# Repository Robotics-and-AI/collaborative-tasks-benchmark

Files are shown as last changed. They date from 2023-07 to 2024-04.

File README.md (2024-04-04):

# Collaborative Tasks Benchmark (CT Benchmark)
<p align="center">
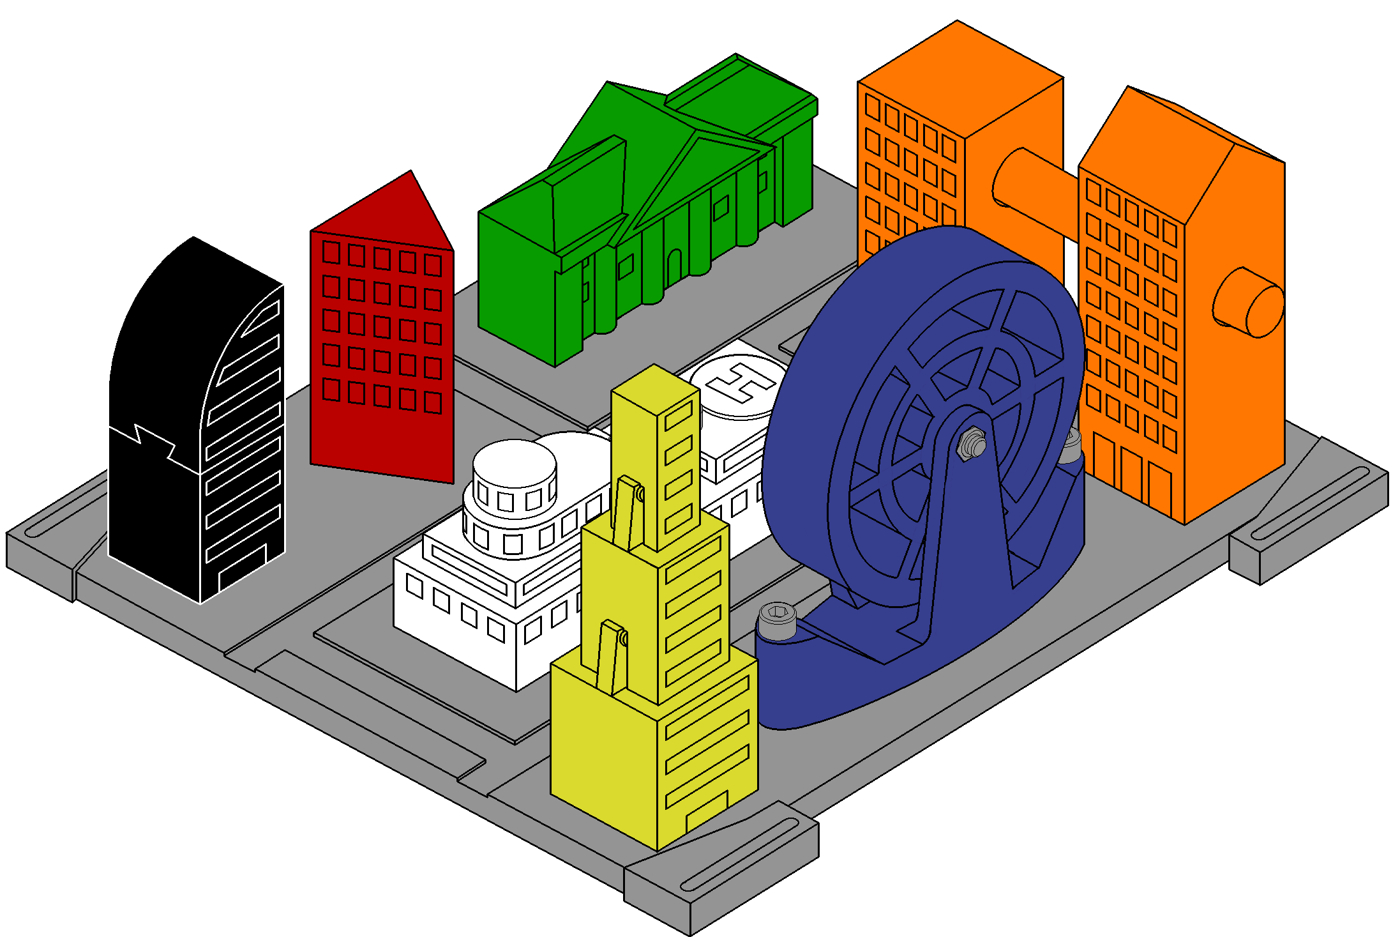
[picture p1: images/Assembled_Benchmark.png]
Assembled benchmark
    
</p>

## Introduction
Benchmarks are crucial to help robotics research advance in an efficient and standardized manner, however, the collaborative assembly field lacks a benchmark with multiple tasks of varying task complexity. As such, we propose the Collaborative Tasks Benchmark (CT Benchmark). It contains 7 distinct tasks ranging from easy to difficult assembly scenarios, each with 1 to 3 parts, providing a rich environment for studying collaborative assembly systems. Its design was grounded on the following criteria:

- Contain independent sequential assembly tasks 
- Tasks have a wide variety of sturdy and graspable 3D printable pieces
- Each piece has its own distinguishable features. 

The benchmark mainly focuses on assisting in the development of collaborative systems, though it is also applicable towards
any combination of its inherent sub-systems: task sequencing allocation, fully-robotic assembly, robot pick-and-place operations and visual perception.

## Task description
The proposed benchmark is representative of a city landscape and contains a total of 7 unique tasks. The main assembly operations are wide tolerance insertion (WTI), tight tolerance insertion (TTI), screw fastening, snap fitting and two-handed actions.

| Task | Color | # sub-tasks | # parts | WTI | TTI | Screw | Snap-fit | Two-handed |
| :---: | :---: | :---: | :-----: | :---: | :---: | :---: | :---: | :---: |
| Museum | green  | 1 | 1 | ✓ | | | | |
| Snap | yellow | 3 | 3 | ✓ | ✓ | | ✓ | |
| Bridge | orange | 3 | 3 | ✓ | ✓ | | | |
| Triangle | red | 1 | 1 | ✓ | | | | |
| Wheel | blue | 3 | 2 | ✓ | | ✓ | | ✓ |
| Dovetail | black  | 2 | 2 | ✓ | ✓ | | | |
| Hospital | white  | 4 | 3 | ✓ | | ✓ | | |

## Benchmark deployment

<table>
  <thead>
    <tr>
      <th>Essential hardware</th>
      <th>Optional hardware</th>
    </tr>
  </thead>
  <tbody>
    <tr>
      <td>
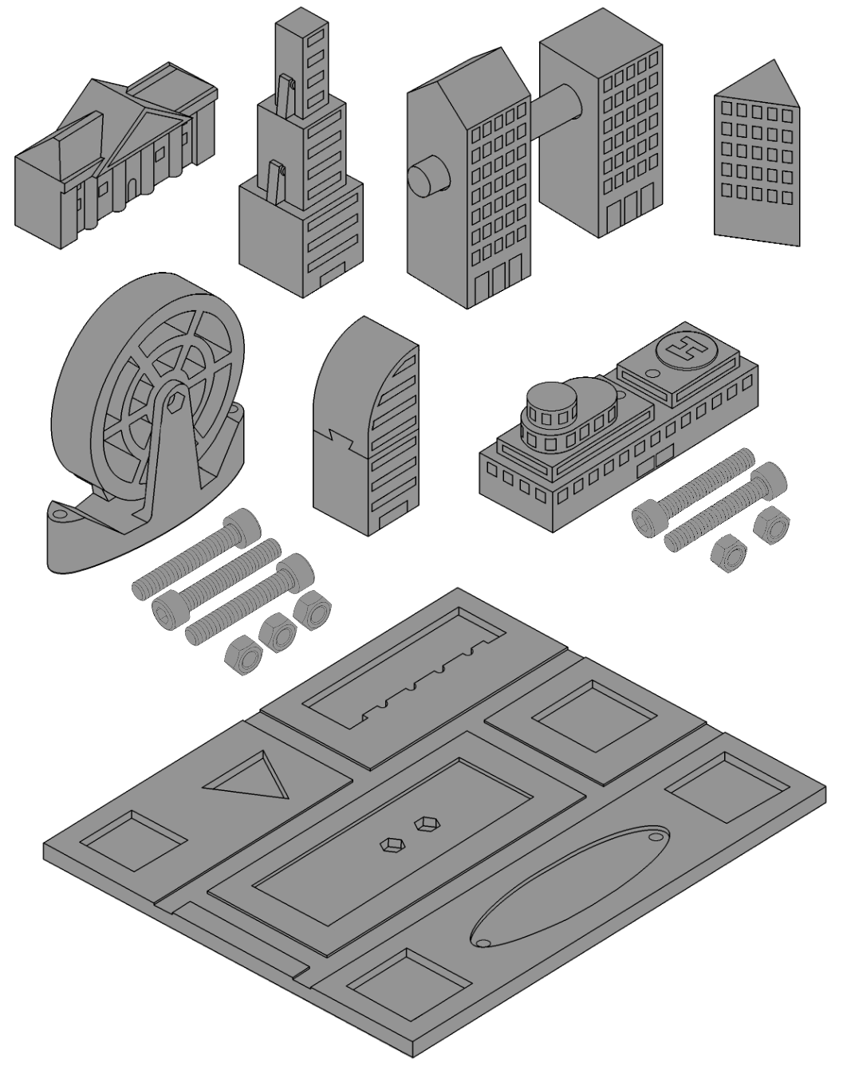
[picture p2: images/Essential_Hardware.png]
Essential Hardware
        
      </td>
      <td>
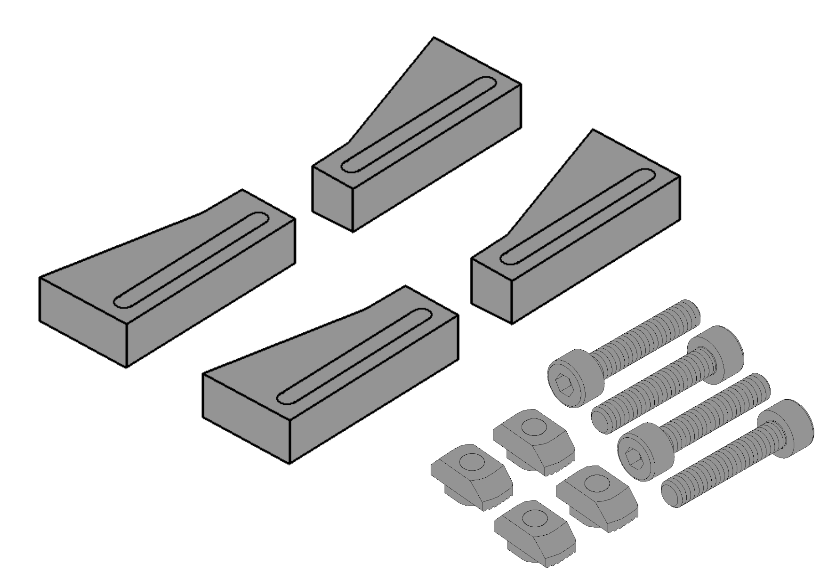
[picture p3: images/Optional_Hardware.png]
Optional Hardware
        
      </td>
    </tr>
    <tr>
      <td>
        <b>3D printed buildings and base:</b>
        <ul>
          <li>520g of PLA</li>
          <li>25 hours</li>
        </ul>
        <b>Fasteners:</b>
        <ul>
          <li>M5 x 30 screws (x5)</li>
          <li>ISO 4032 M5 nuts (x5)</li>
        </ul>
      </td>
      <td>
        <b>3D print corner pieces:</b>
        <ul>
            <li>20g of PLA</li>
            <li>1 hour</li>
          </ul>
          <b>Fasteners:</b>
          <ul>
            <li>M4 x 20 screws (x4)</li>
            <li>Adequately sized M4 T-nuts (x4)</li>
          </ul>
      </td>
    </tr>
  </tbody>
</table>

## Additional material
In addition to the essential and optional hardware, <a href="aditional_stl_files">three supports</a> are made available to aid the assembly process. 
These supports were used to guarantee a repeatable setup in the accompanying article while performing the proposed manufacturing assembly scenarios.

## Cite our paper
If you've found the CT Benchmark useful for your research, please cite our paper as follows:

```
@article{duarte2024benchmarking,
         title = {Benchmarking human-robot collaborative assembly tasks},
         author = {Laura Duarte and 
                   Miguel Neves and 
                   Pedro Neto},
         journal = {Results in Engineering},
         volume = {22},
         year = {2024},
         issn = {2590-1230},
         doi = {10.1016/j.rineng.2024.102042}
}
```

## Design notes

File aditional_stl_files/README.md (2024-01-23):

## Additional 3D printable supports

All supports can be fixed to a T-slot aluminium extrusion frame, with the use of screws and T-nuts.

## Part description

<table>
  
  <thead>
    <tr>
      <th>Image</th>
      <th>Intended use</th>
    </tr>
  </thead>
  
  <tbody>
    <tr>
      <td>
        <p align="center">
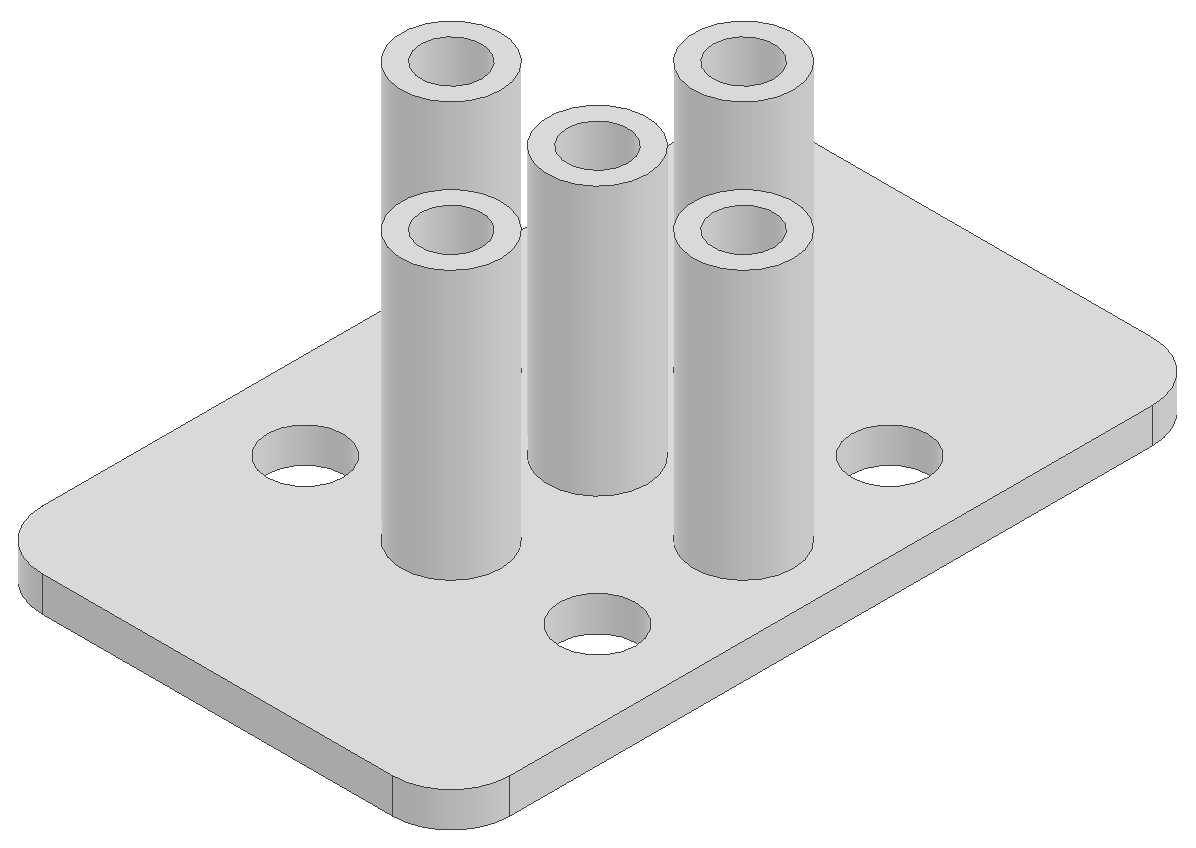
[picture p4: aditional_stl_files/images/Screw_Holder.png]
Screw holder
          </td>
        </p>
      <td>
        Hold the screws in an upright position for easy access to the user
        
        <b>Fasteners:</b>
          <ul>
            <li>M6 x 12 screws (x2)</li>
            <li>Adequately sized M6 T-nuts (x2)</li>
          </ul>
      </td>
    </tr>
    <tr>
      <td>
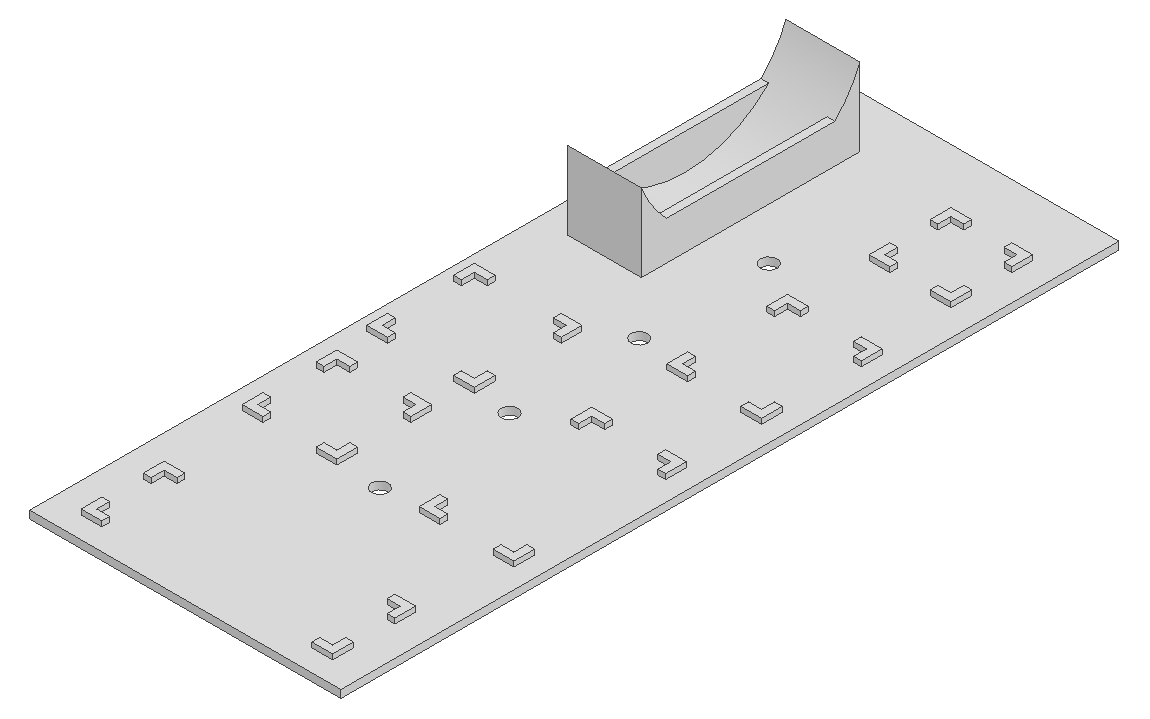
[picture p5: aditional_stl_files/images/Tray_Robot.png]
Tray for robot
          </td>
      <td>
        Hold the benchmark parts intended to be picked up by the collaborative robot
        
        <b>Fasteners:</b>
          <ul>
            <li>M6 x 12 screws (x4)</li>
            <li>Adequately sized M6 T-nuts (x4)</li>
          </ul>
      </td>
    </tr>
    <tr>
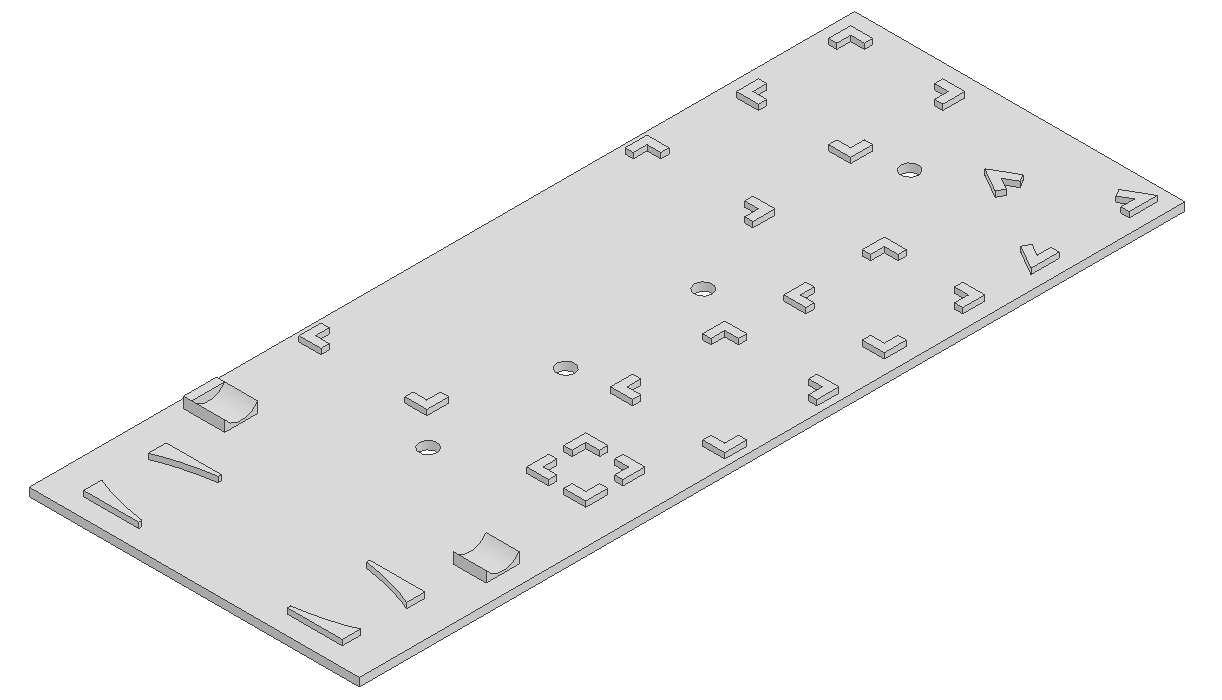
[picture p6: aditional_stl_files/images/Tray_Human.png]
Tray for human
      <td></td>
      <td>
        Hold the benchmark parts intended to be picked up by the human operator
        
        <b>Fasteners:</b>
          <ul>
            <li>M6 x 12 screws (x4)</li>
            <li>Adequately sized M6 T-nuts (x4)</li>
          </ul>
      </td>
    </tr>
  </tbody>
  
</table>

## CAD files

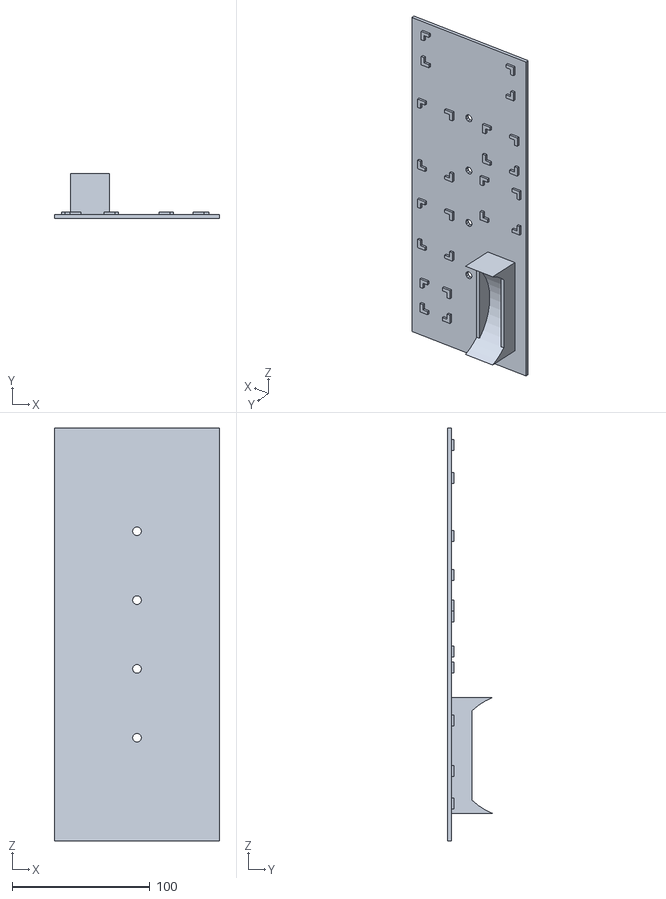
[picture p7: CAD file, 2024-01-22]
aditional_stl_files/stl_files/Tray_Robot.stl
120.0 x 33.0 x 300.0

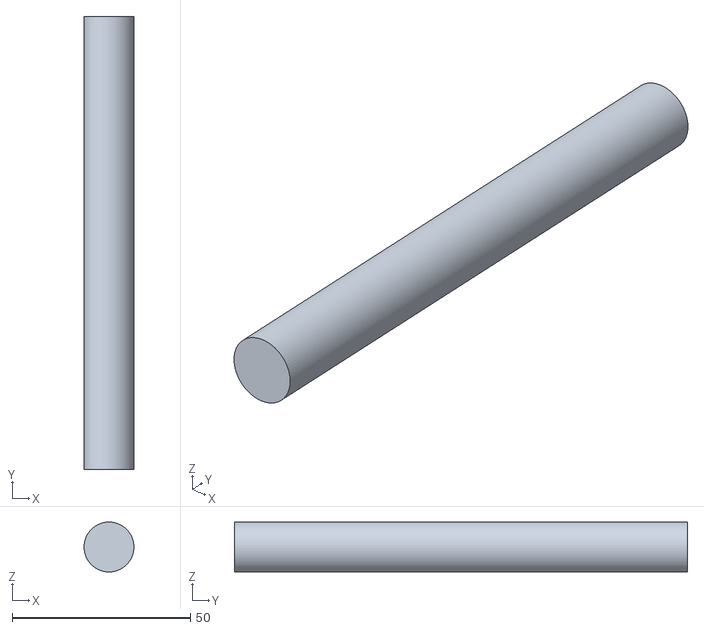
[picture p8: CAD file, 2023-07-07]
stl_files/Bridge/Bridge_Peg.stl
14.0 x 127.0 x 14.0

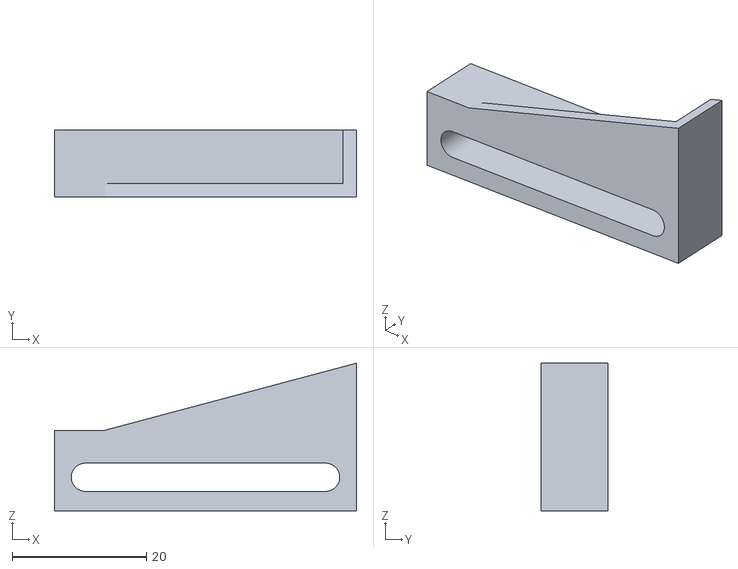
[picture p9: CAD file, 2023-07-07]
stl_files/Corner.stl
45.0 x 10.0 x 22.0

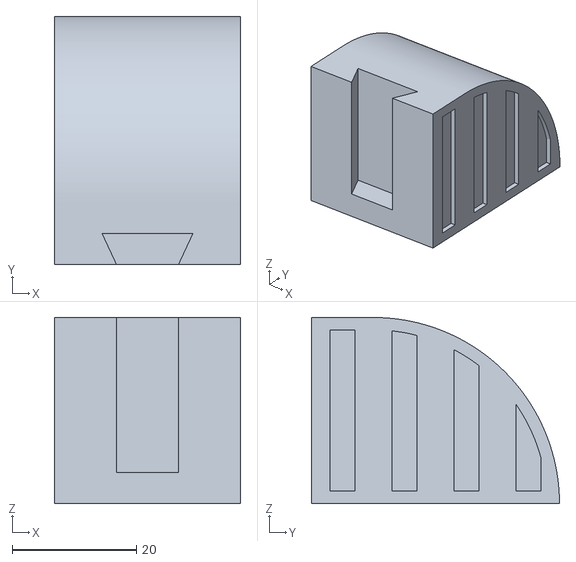
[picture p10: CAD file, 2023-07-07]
stl_files/Dovetail/Dovetail_Top.stl
30.0 x 40.0 x 30.0

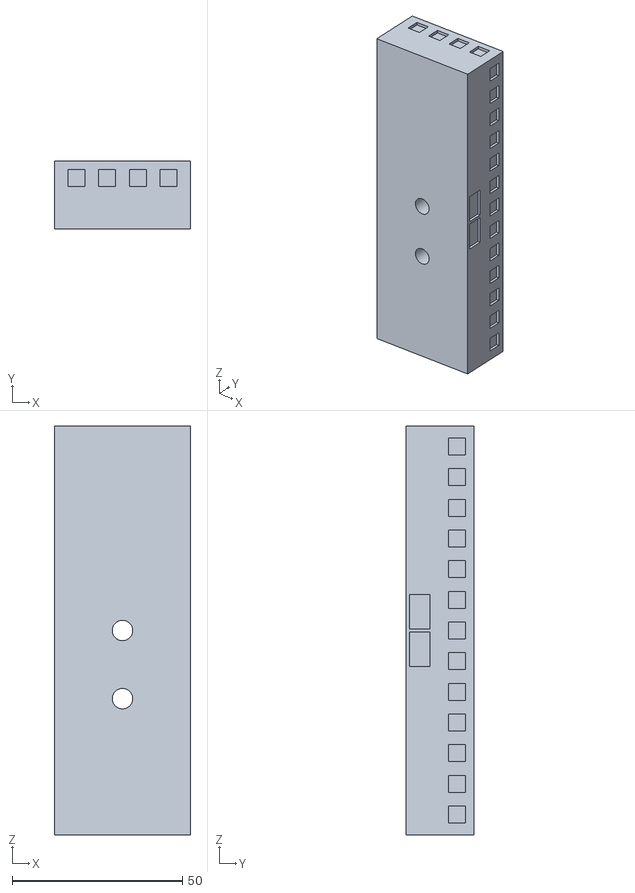
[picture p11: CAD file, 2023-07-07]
stl_files/Hospital/Hospital_Lower.stl
40.0 x 20.0 x 120.0

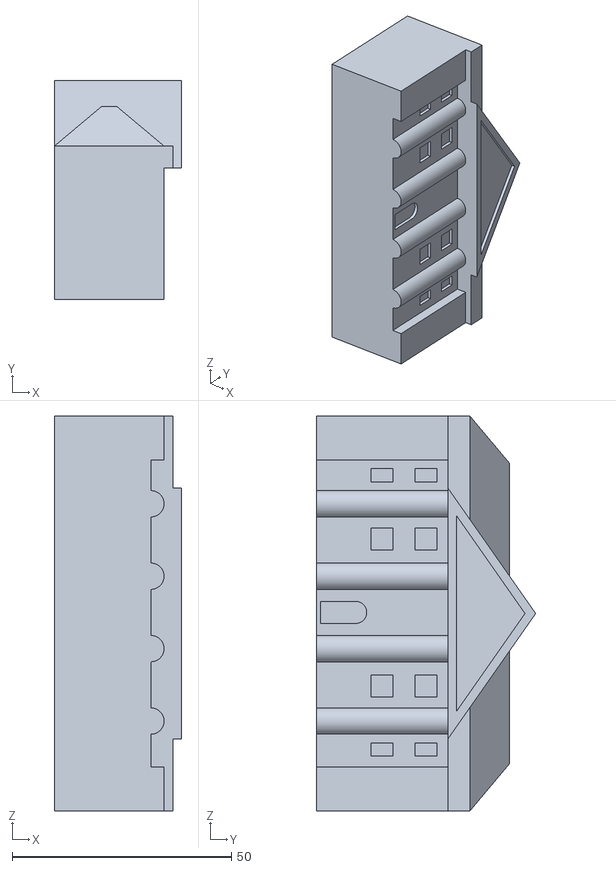
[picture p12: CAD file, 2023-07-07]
stl_files/Museum/Museum.stl
29.0 x 50.0 x 90.0

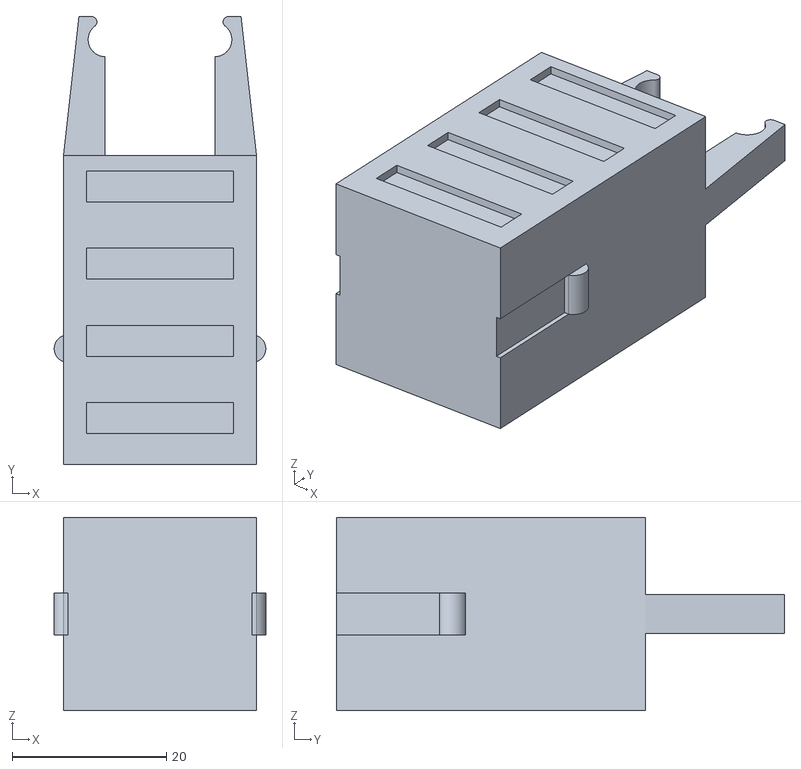
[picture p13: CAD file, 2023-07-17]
stl_files/Snap/Building_Snap_Middle.stl
27.4 x 58.0 x 25.0

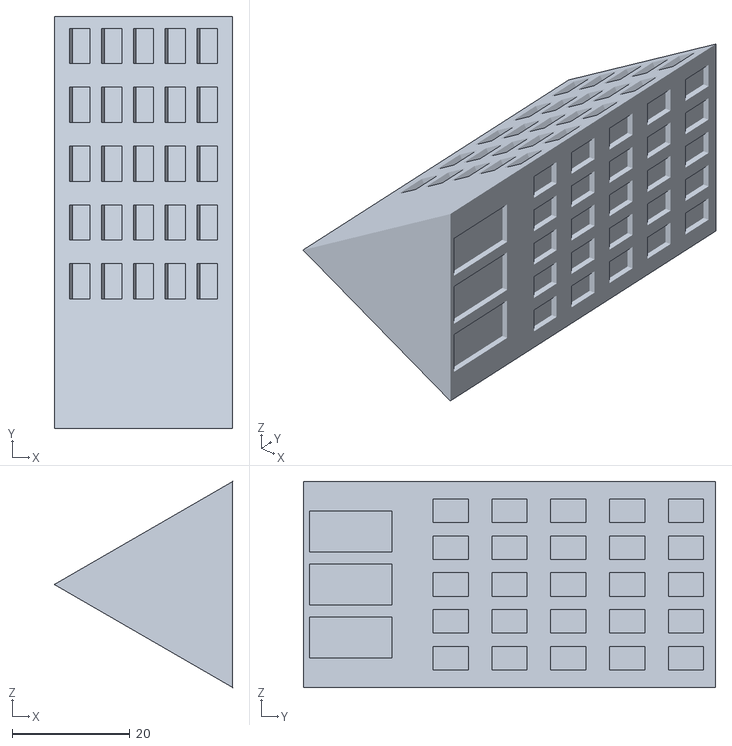
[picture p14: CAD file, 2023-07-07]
stl_files/Triangle/Building_Triangle.stl
30.3 x 70.0 x 35.0

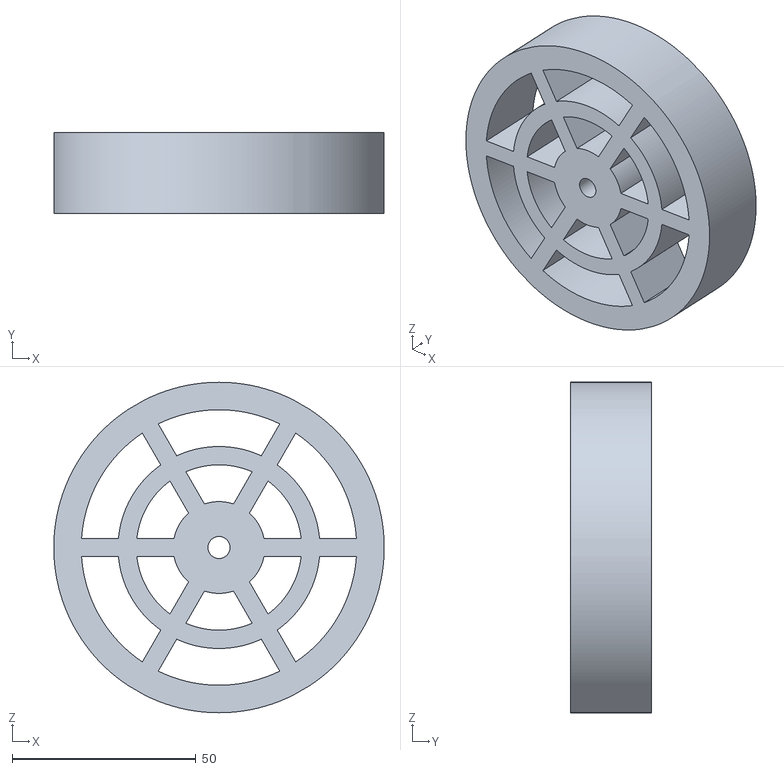
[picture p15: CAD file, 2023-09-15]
stl_files/Wheel/Wheel.stl
89.9 x 22.0 x 90.0

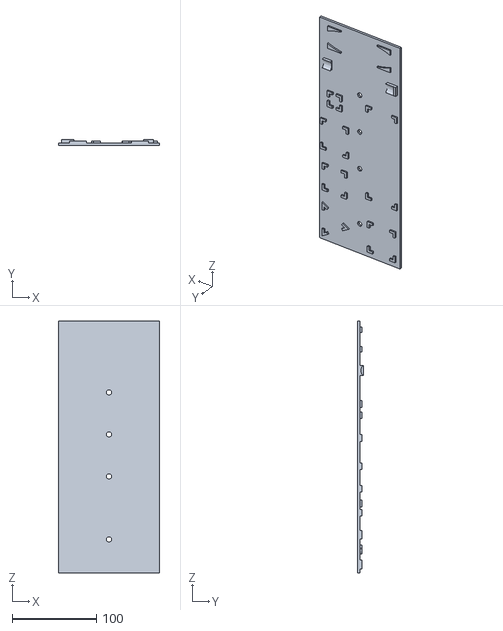
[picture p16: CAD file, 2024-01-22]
aditional_stl_files/stl_files/Tray_Human.stl
120.0 x 6.93 x 300.0

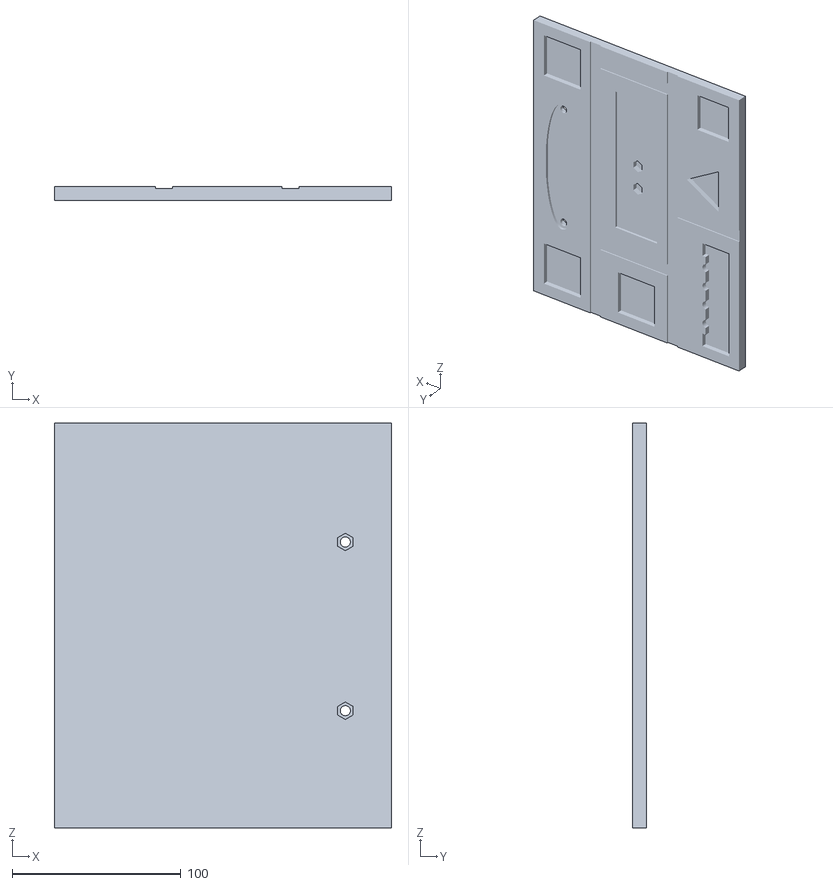
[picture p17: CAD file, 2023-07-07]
stl_files/Base.stl
200.0 x 8.00 x 240.0

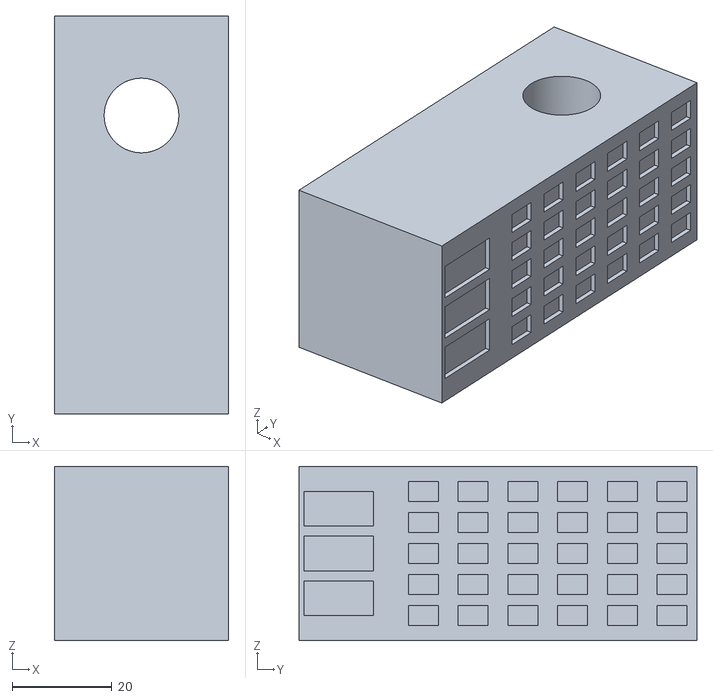
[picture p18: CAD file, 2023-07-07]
stl_files/Bridge/Bridge_Flat.stl
35.0 x 80.0 x 35.0

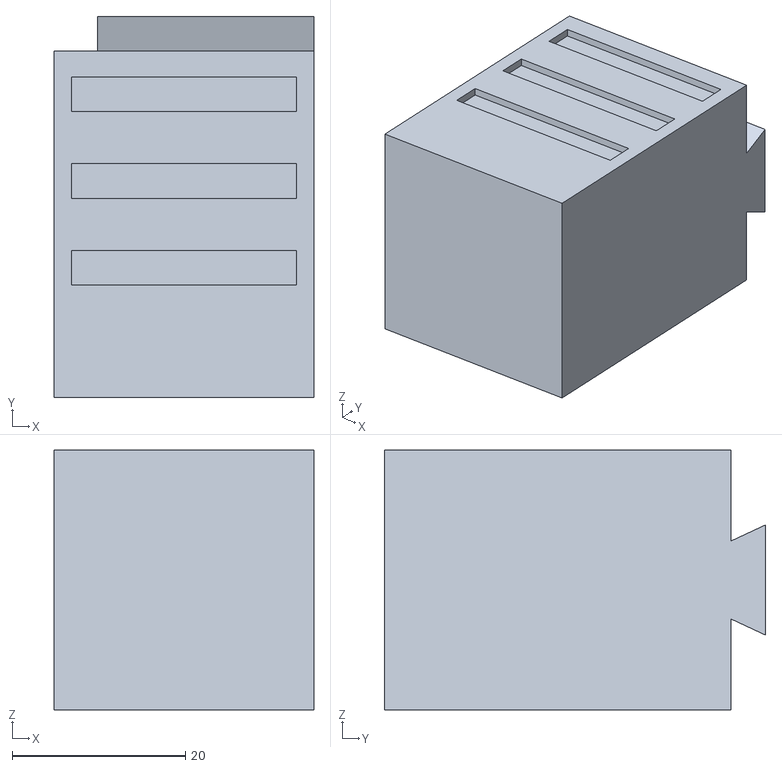
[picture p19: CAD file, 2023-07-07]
stl_files/Dovetail/Dovetail_Lower.stl
30.0 x 44.0 x 30.0

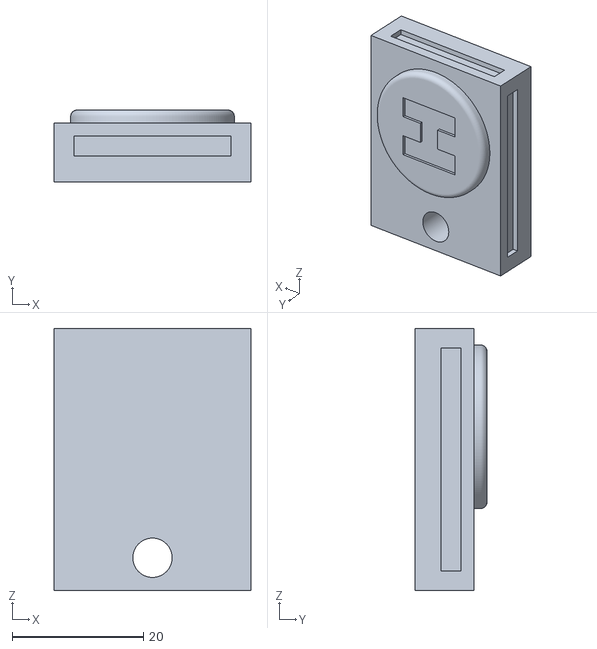
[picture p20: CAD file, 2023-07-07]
stl_files/Hospital/Hospital_Helipad.stl
30.0 x 11.0 x 40.0

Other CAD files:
stl_files/Snap/Building_Snap_Top.stl
stl_files/Wheel/Wheel_Base.stl
stl_files/Bridge/Bridge_Roof.stl
stl_files/Corner_MIR.stl
aditional_stl_files/stl_files/Screw_Holder.stl
stl_files/Hospital/Hospital_Top.stl
stl_files/Snap/Building_Snap_Lower.stl

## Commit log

2023-09-15 Update wheel models
    [Wheel.stl, Wheel_Base.stl]
2023-09-15 Add files via upload
    Correction of Wheel image
2023-12-18 Add assembly steps file
2024-01-22 Added screw_holder .stl file
    [Screw_Holder.stl]
2024-01-22 Change .stl file location
    [Screw_Holder.stl]
